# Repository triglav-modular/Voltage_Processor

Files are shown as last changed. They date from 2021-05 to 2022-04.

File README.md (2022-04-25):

# Triglav Modular Voltage Processor
Eurorack voltage processor / ring modulator inspired by the Buchla 257.

Features:

* Two independent channels, each mixing an attenuverter, a voltage-controlled crossfader and an offset voltage (0-5V).
* „Ring” switches turn the crossfaders into ring modulators / bipolar VCAs.
* S-curve attenuverters for easier nulling.
* Can be trimmed precisely for 1V/oct signals
* LEDs indicating negative/positive voltage.

Other notes:
* Crossfader expects a 0-8V envelope in regular mode.
* Turning on the ring switch normalizes an inverted copy of the inputs into each other. This allows the crossfader to be used as a second attenuverter, a bipolar VCA or a ring modulator with adjustable bias without any additonal patching.
* 11 HP, compact design
* Panel + PCB sandwich, suitable for skiffs
* Reverse polarity protection
* Open source




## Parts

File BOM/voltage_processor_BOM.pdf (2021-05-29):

Designator | Package | Quantity | Value

Resistors

R72,R69,R28,R71,R30,R33,R74,R31 0805 | 8 | 220R
R21,R90,R48,R49,R44,R85 | 0805 | 6 | 1K
R4,R2,R3,R1 | 0805 | 4 | 2K2
R106,R105,R109,R108 | 0805 | 4 | 4K7
R7,R8,R5,R6,R89,R104 | 0805 | 6 | 10K
R36,R39 | 0805 | 2 | 80K
R78,R37,R45,R96 | 0805 | 4 | 49K9
R26,R68,R75,R22,R102,R63,R103,R10,R19,R15,R52,R38,R18,R88,R13,R51,R27,R70,R50,R67,R12,R35,R56,R54,R62,R40,R43,R24,R29,R59,R65,R87,R41,R82,R11,R60,R53,R73,R47,R34,R95,R46,R76,R42 0805 | 44 | 100K
R58,R61,R16,R23,R25,R55,R66,R17,R20,R64,R14,R57 0805 | 12 | 200K
R110,R107 | 0805 | 2 | 442K
R32,R9 | 0805 | 2 | 10M

Capacitors

C54,C70 | 0805 | 2 | 33p
CS | 0805 | 15 | do not fit or 33p
C27,C10,C29,C12 | 0805 | 4 | 100p
C31,C30,C15,C28,C32,C11,C13,C14 0805 | 8 | 1200p
C25,C62,C46,C68,C56,C36,C23,C52,C21,C55,C22,C35,C20,C61,C24,C6,C67,C37,C45,C38,C5,C18,C51,C19 0805 | 24 | 0.1µ
C1,C4,C3,C2 | Ø4x5.8mm (Panasonic B) eg. EEEFT1E220AR 4 | 22µ

Semiconductors

U1,U9,U8,U11,U4,U5 | SOIC-14 | 6 | OPA4134 / TL074
IC3,IC2,IC4,IC1 | SOIC-16 | 4 | DG212BDY
U10,U6 | SOIC-16 | 2 | SSI2164
D1,D2 | D_SOD-123 | 2 | 1N5819
Q3,Q1 | SOT-23-3 | 2 | 3906
Q4,Q2 | SOT-23-3 | 2 | 3904
U2 | SOT-89-3 | 1 | L78L05
D6,D3,D4,D5 | LED 3.0mm | 4 | LED
D7,D8,D9,D10 | D_SOD-323 | 4 | Zener 5.1V

Miscellaneous

| Alpha 9mm vertical potentiometer | 6 | B10K
| THONKICONN Jacks | 10
| Eurorack Keyed Header | 1 | 30310-6002HB
ATV_COMP2,CRSFD2,ATV_COMP1,LED1+1,LED2+1,LED2-1,LED1-1,CRSFD1 BOURNS 3362P TRIMMER | 8 | 100K
S1,S2 | 108-2MS1T1B1M2QE-EVX | 2 | SPDT Sub-Miniature Toggle Switch
PinHeader_1x10_P2.54mm_Vertical2 | Conn_01x10_Female
PinHeader_1x10_P2.54mm_Vertical2 | Conn_01x10_Male
PinHeader_1x16_P2.54mm_Vertical1 | Conn_01x16_Male
PinHeader_1x16_P2.54mm_Vertical1 | Conn_01x16_Female

1

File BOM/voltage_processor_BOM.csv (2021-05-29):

Id | Designator | Package | Quantity | Designation | Supplier and ref
1 | R26,R68,R75,R22,R102,R63,R103,R10,R19,R15,R52,R38,R18,R88,R13,R51,R27,R70,R50,R67,R12,R35,R56,R54,R62,R40,R43,R24,R29,R59,R65,R87,R41,R82,R11,R60,R53,R73,R47,R34,R95,R46,R76,R42 | R_0805_2012Metric | 44 | 100K
2 | R78,R37,R45,R96 | R_0805_2012Metric | 4 | 49K9
3 | ATV_COMP2,CRSFD2,ATV_COMP1,LED1+1,LED2+1,LED2-1,LED1-1,CRSFD1 | BOURNS_3362P_TRIMMER | 8 | 100K
4 | R58,R61,R16,R23,R25,R55,R66,R17,R20,R64,R14,R57 | R_0805_2012Metric | 12 | 200K
5 | IC3,IC2,IC4,IC1 | SOIC-16_3.9x9.9mm_P1.27mm | 4 | DG212BDY
6 | J10,J14 | THONKICONN | 2 | OUTPUT
7 | J7,J11 | THONKICONN | 2 | CROSSFADE_CV
8 | R72,R69,R28,R71,R30,R33,R74,R31 | R_0805_2012Metric | 8 | 220R
9 | C1,C4,C3,C2 | CAPAE430X610N | 4 | 22µ
10 | C31,C30,C15,C28,C32,C11,C13,C14 | C_0805_2012Metric | 8 | 1200p
11 | OFFSET2,OFFSET1,ATNVRT2,ATNVRT1,CROSSFADE2,CROSSFADE1 | MusicThingModular-9MM_SNAP-IN_POT | 6 | B10K
12 | D6,D3,D4,D5 | LED_D3.0mm | 4 | LED
13 | MH8,MH7,MH4,MH2,MH5,MH3,MH6,MH1 | MountingHole_3.2mm_M3 | 8 | MountingHole_3.2mm_M3
14 | R7,R8,R5,R6,R89,R104 | R_0805_2012Metric | 6 | 10K
15 | R21,R90,R48,R49,R44,R85 | R_0805_2012Metric | 6 | 1K
16 | J1,J2 | THONKICONN | 2 | ATNVRT_IN_BOTTOM
17 | R106,R105,R109,R108 | R_0805_2012Metric | 4 | 4K7
18 | J17 | SHDR10W64P254_2X5_2030X878X930P | 1 | 30310-6002HB
19 | U1,U9,U8,U11,U4,U5 | SOIC-14_3.9x8.7mm_P1.27mm | 6 | OPA4134
20 | D7,D8,D9,D10 | D_SOD-323_HandSoldering_ZENER | 4 | Z-5V
21 | R36,R39 | R_0805_2012Metric | 2 | 80K
22 | Q3,Q1 | SOT-23-3 | 2 | 3906
23 | R32,R9 | R_0805_2012Metric | 2 | 10Meg
24 | mouse-bite-2mm-slot_3,mouse-bite-2mm-slot_2,mouse-bite-2mm-slot_1 | mouse-bite-2mm-slot | 3 | VAL**
25 | U10,U6 | SOIC-16_3.9x9.9mm_P1.27mm | 2 | SSI2164
26 | Q4,Q2 | SOT-23-3 | 2 | 3904
27 | J9,J13 | THONKICONN | 2 | CROSSFADE_B
28 | D1,D2 | D_SOD-123 | 2 | 1N5819
29 | J12,J8 | THONKICONN | 2 | CROSSFADE_A
30 | S1,S2 | 1082MS1T1B1M2QEEVX | 2 | 108-2MS1T1B1M2QE-EVX
31 | U2 | SOT-89-3 | 1 | L78L05
32 | C25,C62,C46,C68,C56,C36,C23,C52,C21,C55,C22,C35,C20,C61,C24,C6,C67,C37,C45,C38,C5,C18,C51,C19 | C_0805_2012Metric | 24 | 0.1µ
33 | C8,C42,C66,C7,C43,C50,C63,C65,C64,C59,C17,C47,C48,C49,C58 | C_0805_2012Metric | 15 | CS
34 | R4,R2,R3,R1 | R_0805_2012Metric | 4 | 2K2
35 | J5 | PinHeader_1x16_P2.54mm_Vertical | 1 | Conn_01x16_Male
36 | J6,J4 | PinHeader_1x10_P2.54mm_Vertical | 2 | Conn_01x10_Female
37 | R110,R107 | R_0805_2012Metric | 2 | 442K
38 | J15,J16 | PinHeader_1x10_P2.54mm_Vertical | 2 | Conn_01x10_Male
39 | C27,C10,C29,C12 | C_0805_2012Metric | 4 | 100p
40 | J3 | PinHeader_1x16_P2.54mm_Vertical | 1 | Conn_01x16_Female
41 | C54,C70 | C_0805_2012Metric | 2 | 33p

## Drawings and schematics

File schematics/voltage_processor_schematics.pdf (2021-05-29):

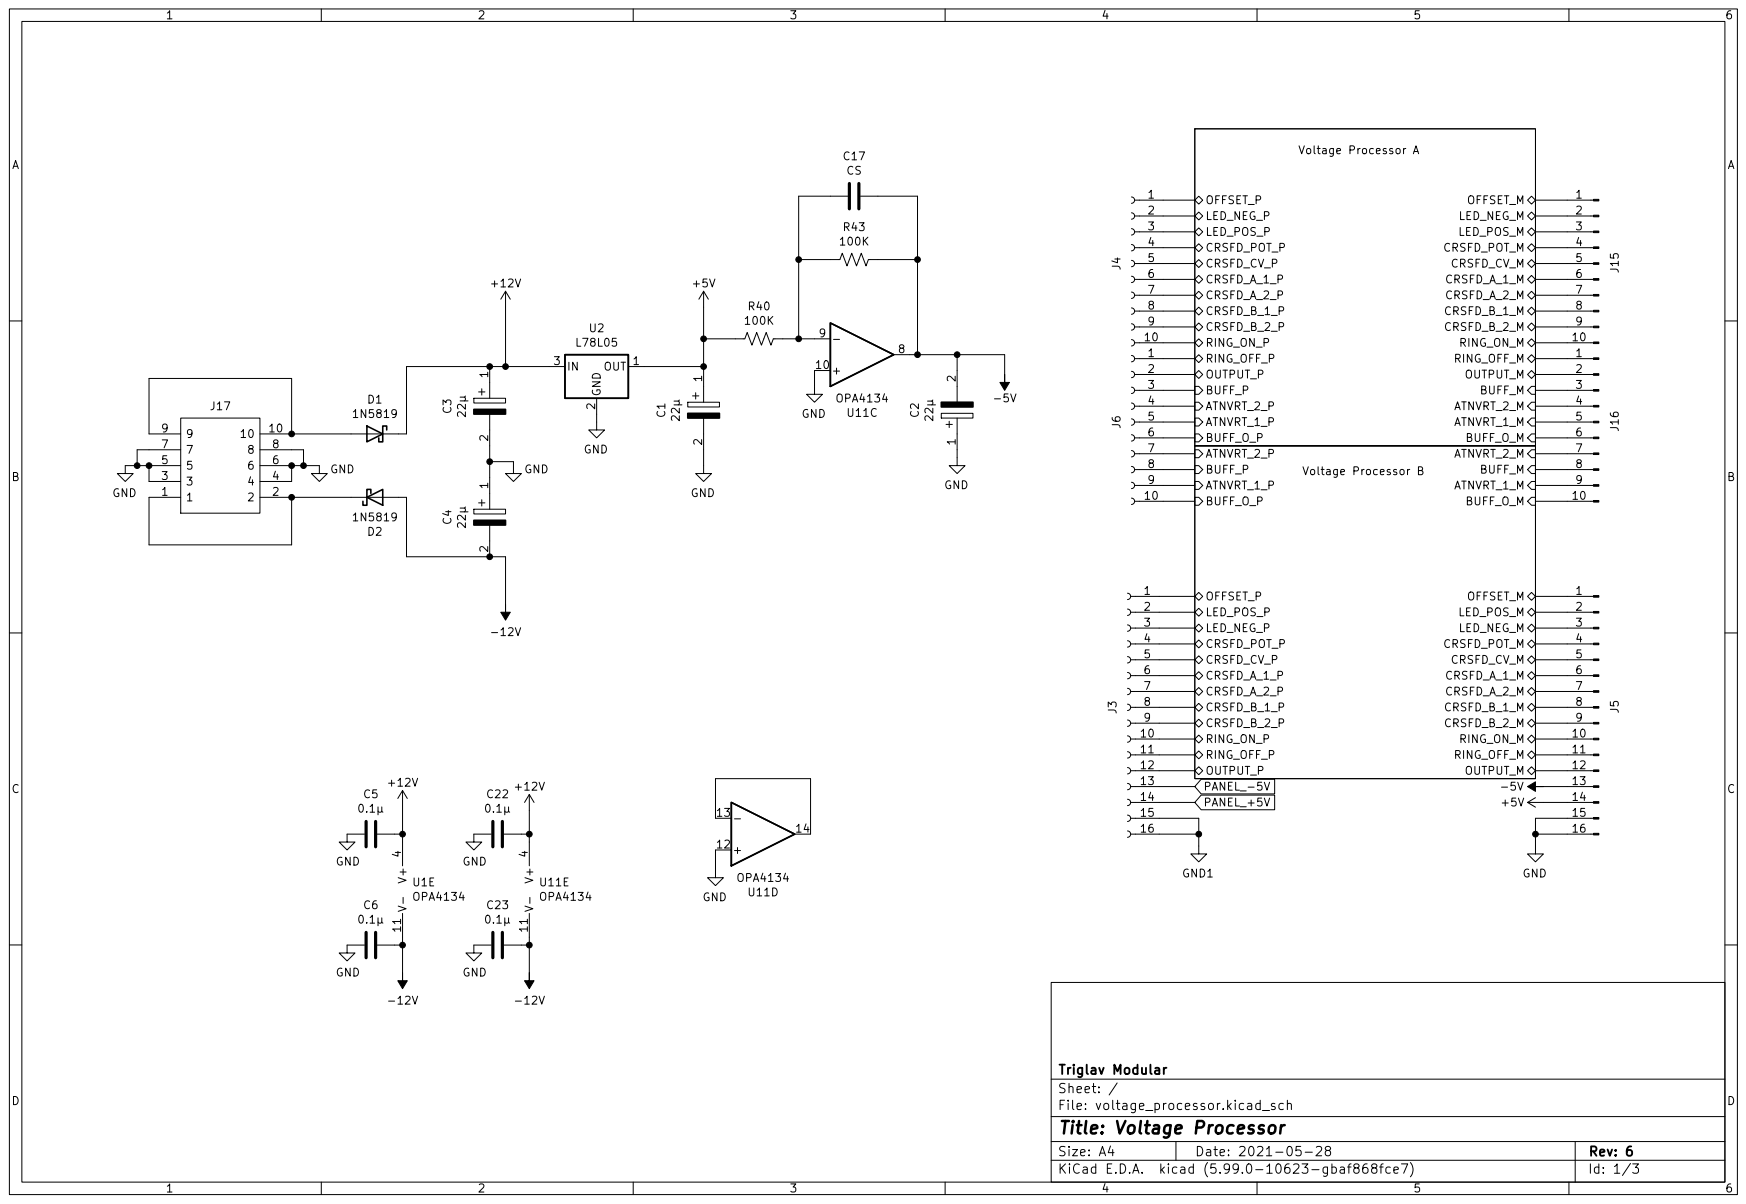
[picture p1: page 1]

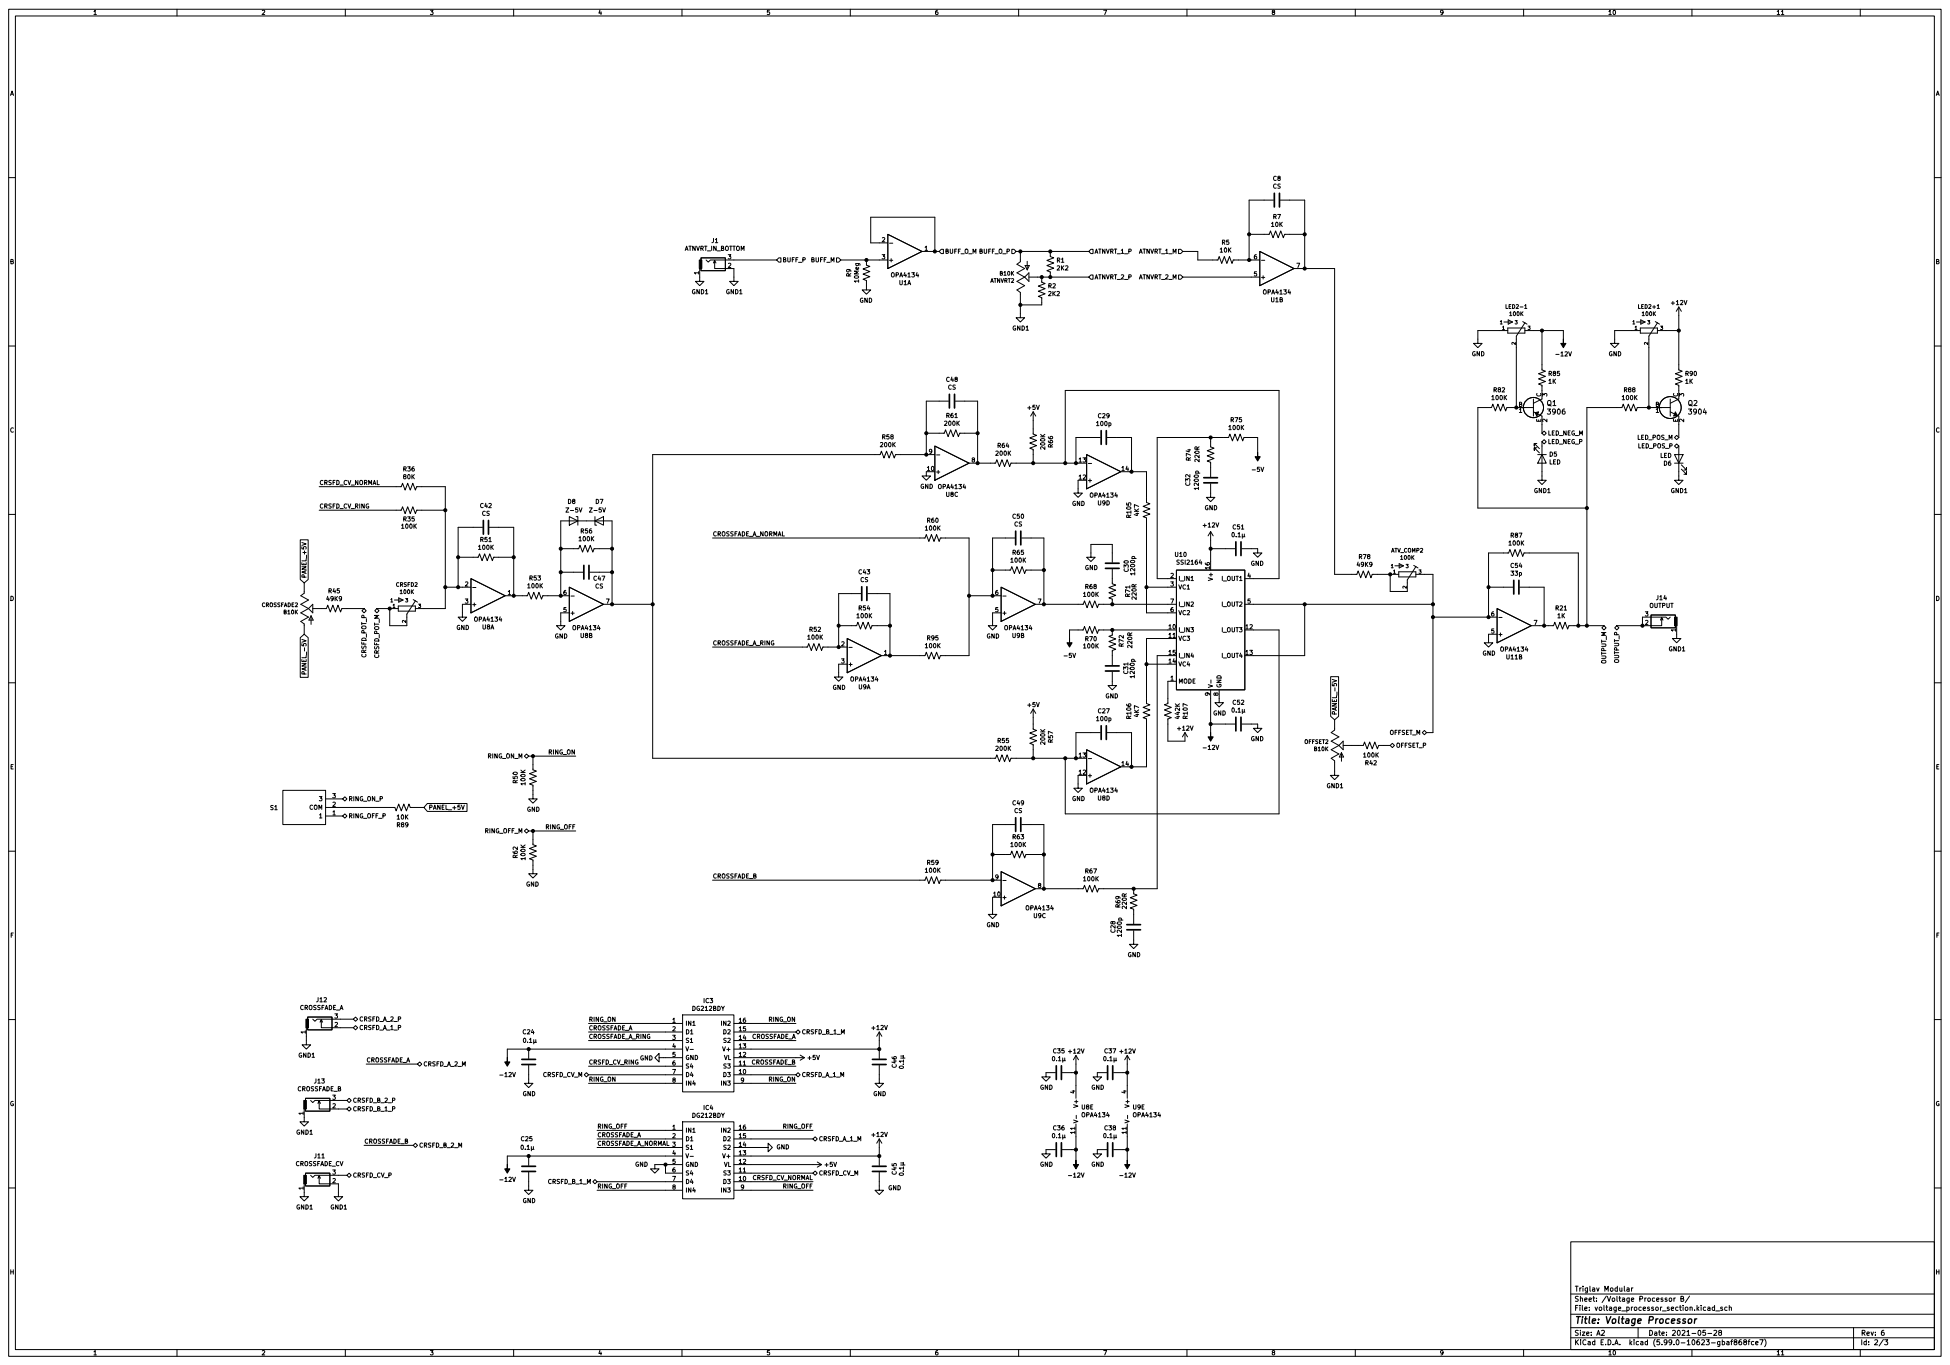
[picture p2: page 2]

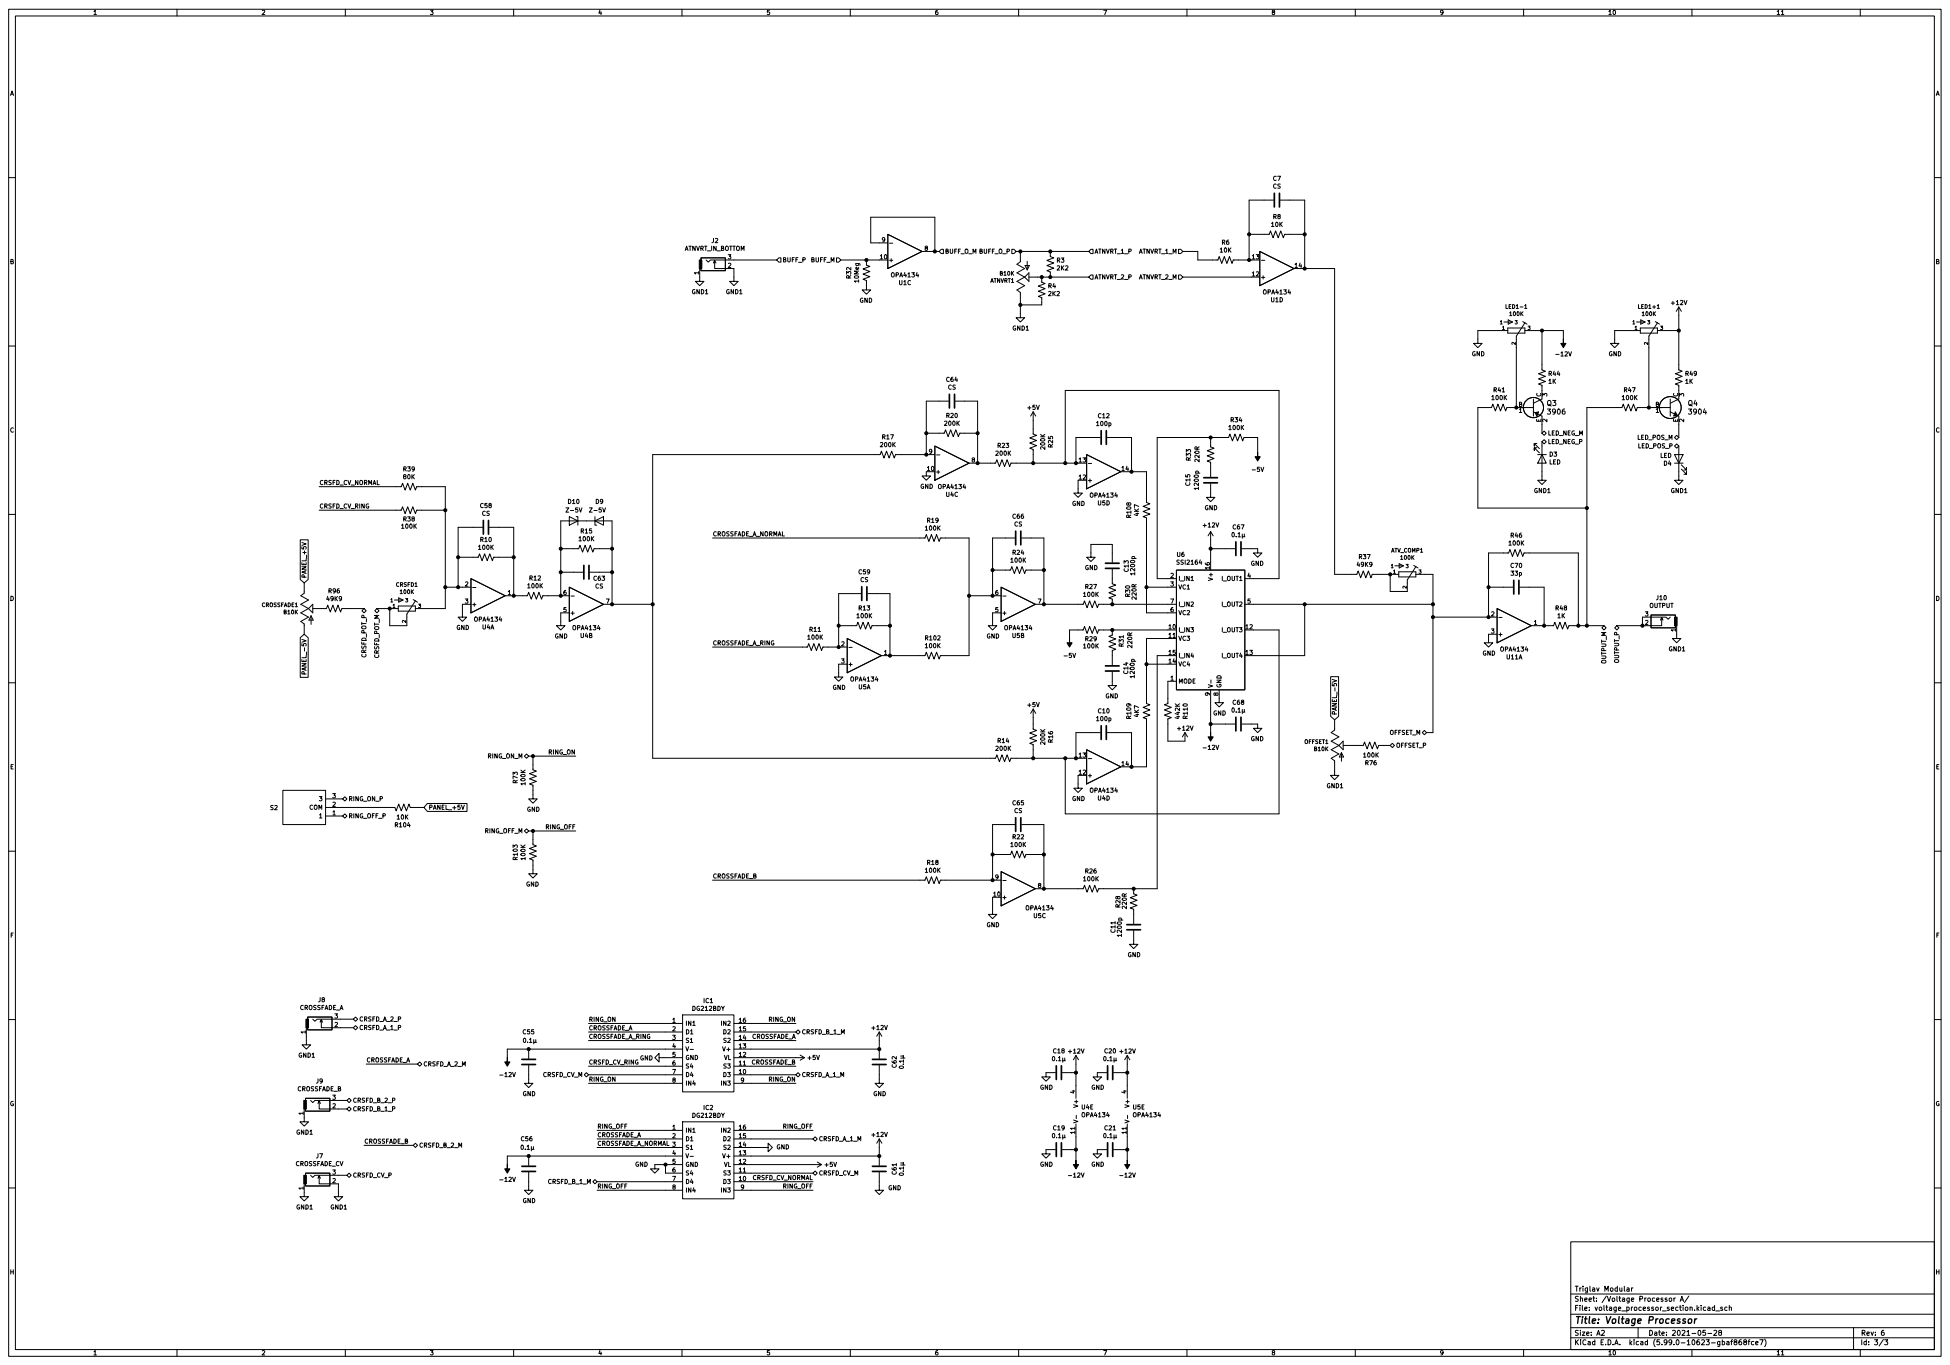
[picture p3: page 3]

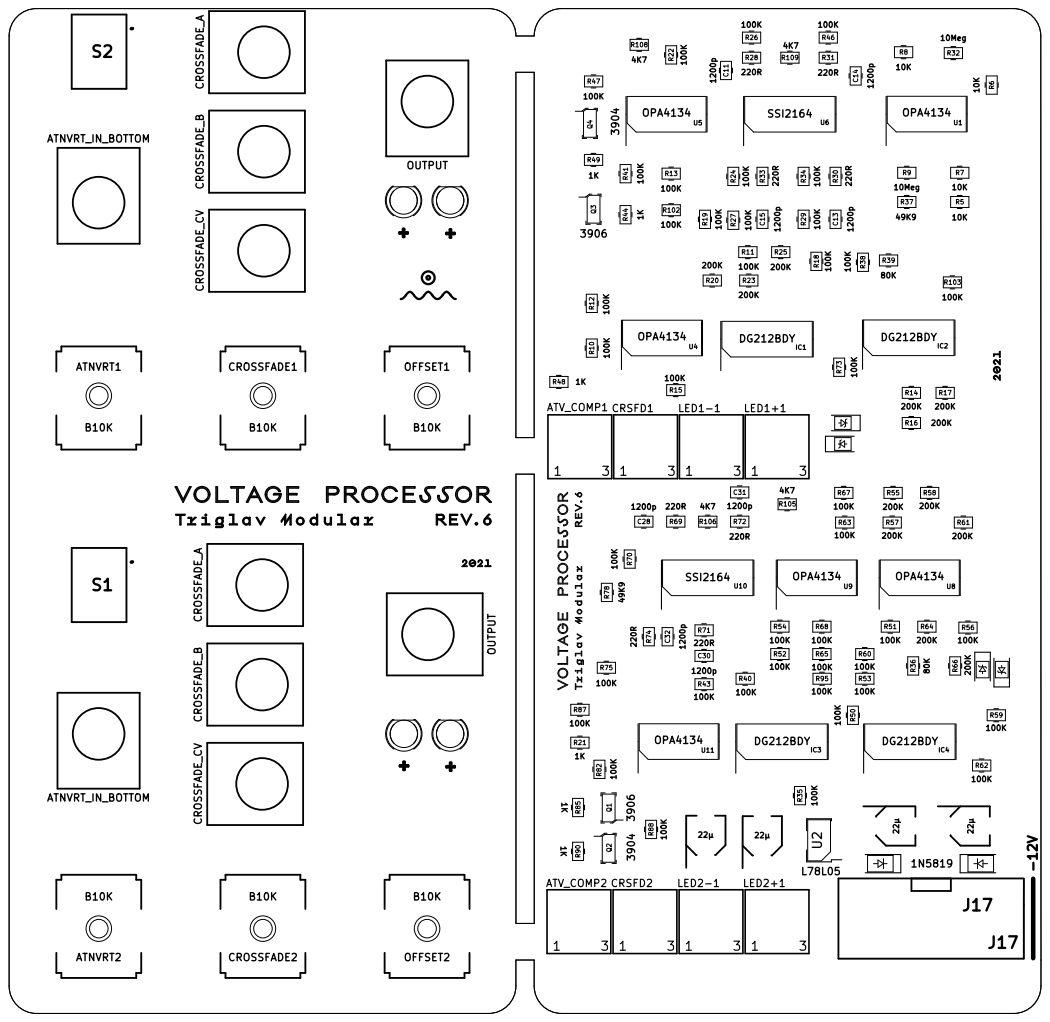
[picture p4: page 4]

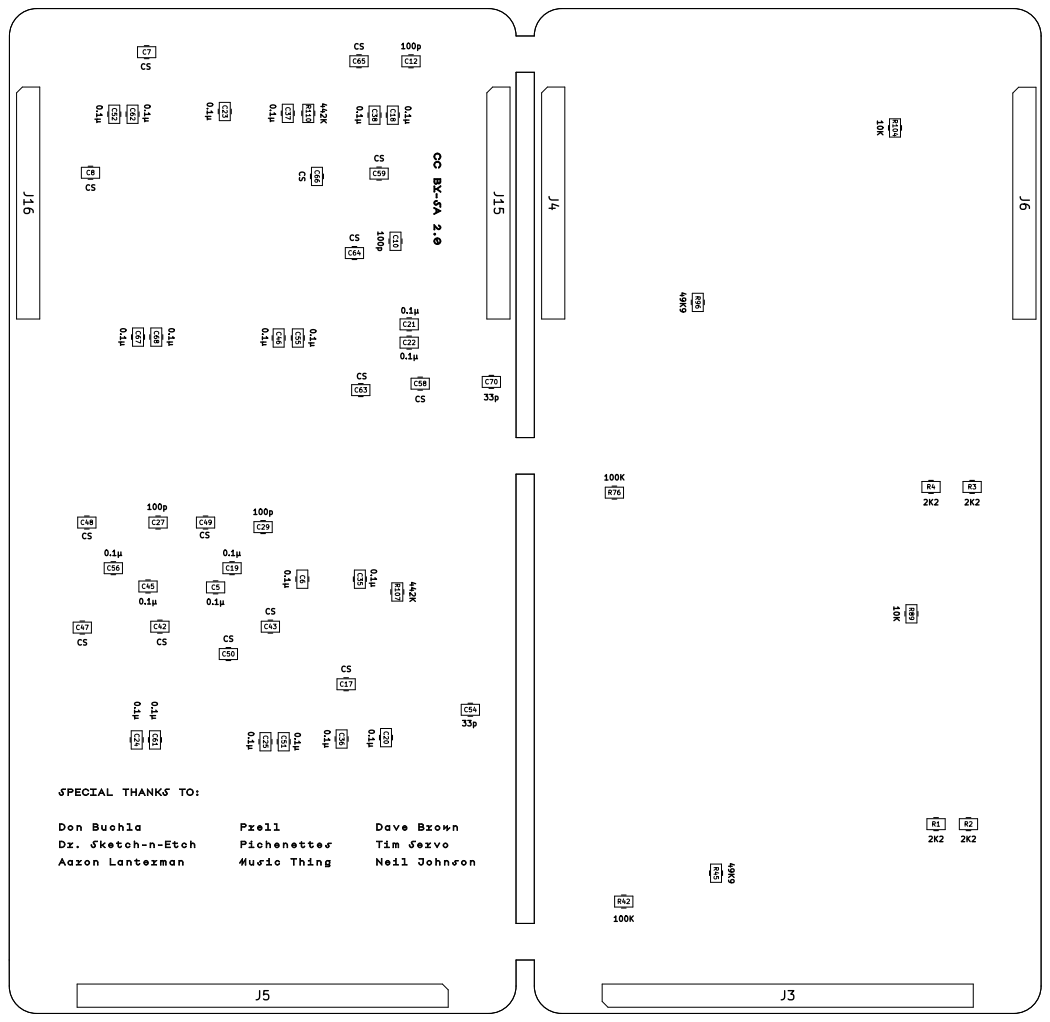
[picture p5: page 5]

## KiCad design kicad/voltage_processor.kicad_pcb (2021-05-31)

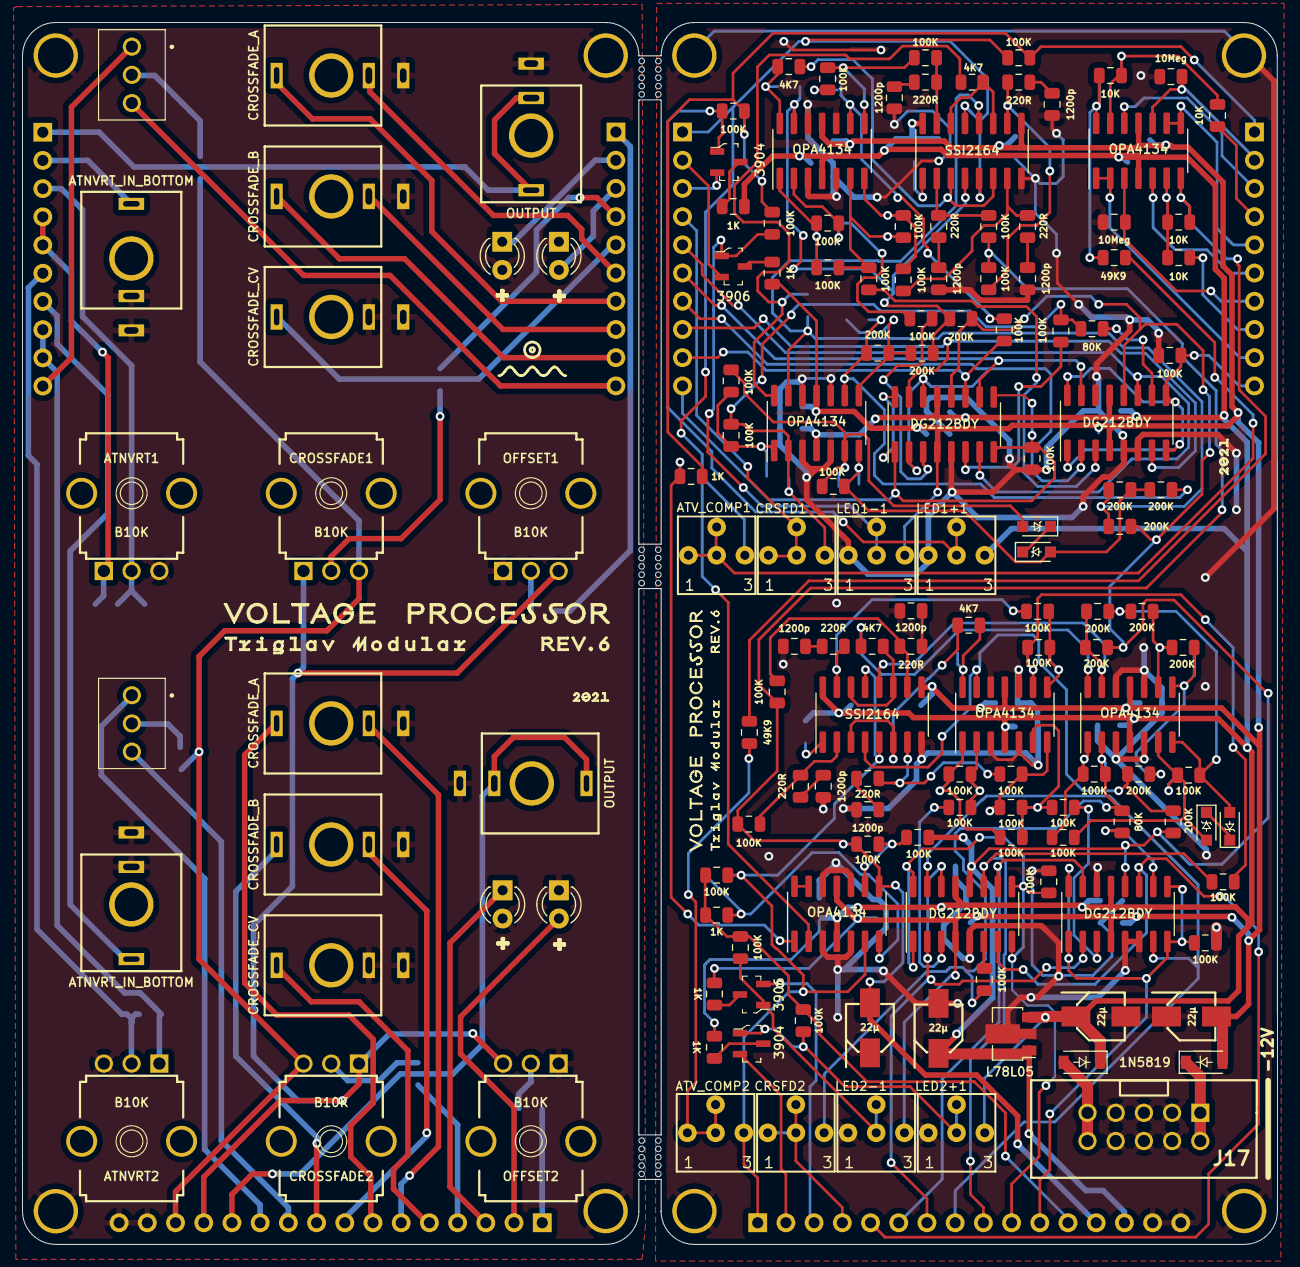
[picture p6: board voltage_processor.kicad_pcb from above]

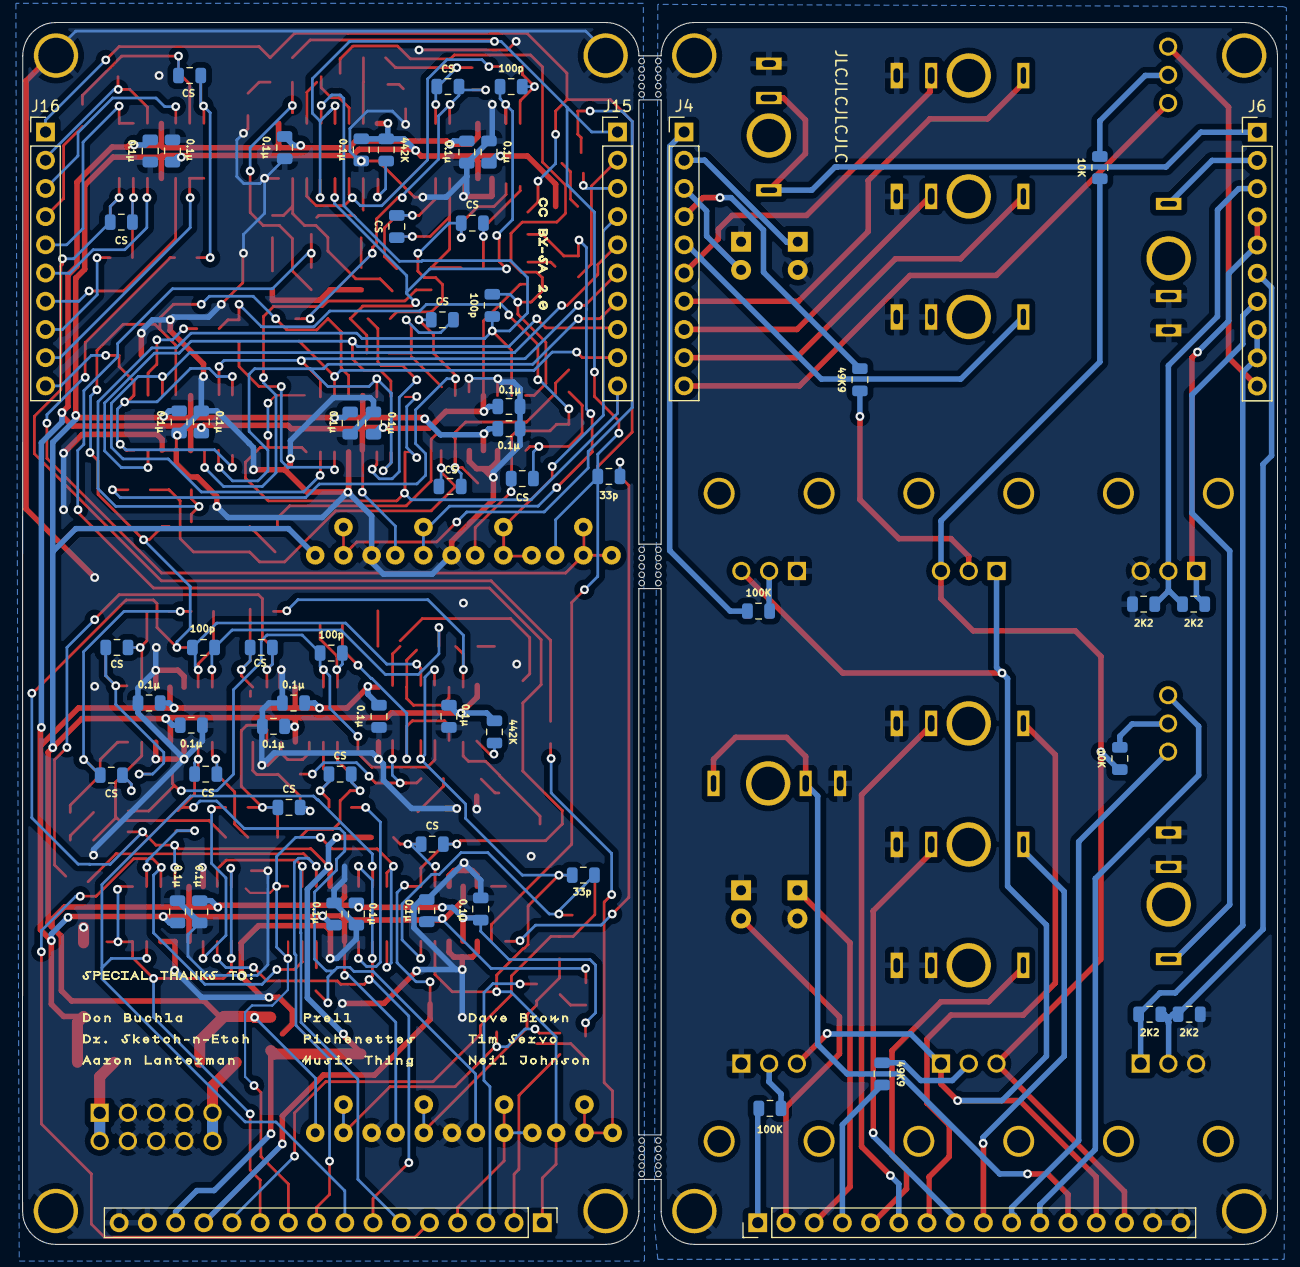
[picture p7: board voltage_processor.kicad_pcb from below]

Board: 2 copper layers, 113.0 x 110.0 mm, 222 parts (63 on the bottom side), 160 nets.

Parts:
ATNVRT1, ATNVRT2: B10K; MusicThingModular-9MM_SNAP-IN_POT
ATV_COMP1, ATV_COMP2: 100K; BOURNS_3362P_TRIMMER
C1, C2, C3, C4: 22µ; CAPAE430X610N
C5, C6, C18, C19, C20, C21, C22, C23, C24, C25, C35, C36, C37, C38, C45, C46, C51, C52, C55, C56, C61, C62, C67, C68: 0.1µ; C_0805_2012Metric
C7, C8, C17, C42, C43, C47, C48, C49, C50, C58, C59, C63, C64, C65, C66: CS; C_0805_2012Metric
C10, C12, C27, C29: 100p; C_0805_2012Metric
C11, C13, C14, C15, C28, C30, C31, C32: 1200p; C_0805_2012Metric
C54, C70: 33p; C_0805_2012Metric
CROSSFADE1, CROSSFADE2: B10K; MusicThingModular-9MM_SNAP-IN_POT
CRSFD1, CRSFD2: 100K; BOURNS_3362P_TRIMMER
D1, D2: 1N5819; D_SOD-123
D3, D4, D5, D6: LED; LED_D3.0mm
D7, D8, D9, D10: Z-5V; D_SOD-323_HandSoldering_ZENER
IC1, IC2, IC3, IC4: DG212BDY; SOIC-16_3.9x9.9mm_P1.27mm
J1, J2: ATNVRT_IN_BOTTOM; THONKICONN
J3: Conn_01x16_Female; PinHeader_1x16_P2.54mm_Vertical
J4, J6: Conn_01x10_Female; PinHeader_1x10_P2.54mm_Vertical
J5: Conn_01x16_Male; PinHeader_1x16_P2.54mm_Vertical
J7, J11: CROSSFADE_CV; THONKICONN
J8, J12: CROSSFADE_A; THONKICONN
J9, J13: CROSSFADE_B; THONKICONN
J10, J14: OUTPUT; THONKICONN
J15, J16: Conn_01x10_Male; PinHeader_1x10_P2.54mm_Vertical
J17: 30310-6002HB; SHDR10W64P254_2X5_2030X878X930P
LED1+1, LED1-1, LED2+1, LED2-1: 100K; BOURNS_3362P_TRIMMER
MH1, MH2, MH3, MH4, MH5, MH6, MH7, MH8: MountingHole_3.2mm_M3
OFFSET1, OFFSET2: B10K; MusicThingModular-9MM_SNAP-IN_POT
Q1, Q3: 3906; SOT-23-3
Q2, Q4: 3904; SOT-23-3
R1, R2, R3, R4: 2K2; R_0805_2012Metric
R5, R6, R7, R8, R89, R104: 10K; R_0805_2012Metric
R9, R32: 10Meg; R_0805_2012Metric
R10, R11, R12, R13, R15, R18, R19, R22, R24, R26, R27, R29, R34, R35, R38, R40, R41, R42, R43, R46, R47, R50, R51, R52, R53, R54, R56, R59, R60, R62, R63, R65, R67, R68, R70, R73, R75, R76, R82, R87, R88, R95, R102, R103: 100K; R_0805_2012Metric
R14, R16, R17, R20, R23, R25, R55, R57, R58, R61, R64, R66: 200K; R_0805_2012Metric
R21, R44, R48, R49, R85, R90: 1K; R_0805_2012Metric
R28, R30, R31, R33, R69, R71, R72, R74: 220R; R_0805_2012Metric
R36, R39: 80K; R_0805_2012Metric
R37, R45, R78, R96: 49K9; R_0805_2012Metric
R105, R106, R108, R109: 4K7; R_0805_2012Metric
R107, R110: 442K; R_0805_2012Metric
S1, S2: 108-2MS1T1B1M2QE-EVX; 1082MS1T1B1M2QEEVX
U1, U4, U5, U8, U9, U11: OPA4134; SOIC-14_3.9x8.7mm_P1.27mm
U2: L78L05; SOT-89-3
U6, U10: SSI2164; SOIC-16_3.9x9.9mm_P1.27mm
mouse-bite-2mm-slot_1, mouse-bite-2mm-slot_2, mouse-bite-2mm-slot_3: VAL**; mouse-bite-2mm-slot

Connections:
+5V: C1.1, IC1.12 (VL), IC2.12 (VL), IC3.12 (VL), IC4.12 (VL), J5.14, R16.2, R25.2, R40.2, R57.2, R66.2, U2.1 (OUT)
+12V: C3.1, C5.1, C18.1, C20.1, C22.1, C35.1, C37.1, C45.1, C46.2, C51.1, C61.1, C62.2, C67.1, D1.1 (K), IC1.13 (V+), IC2.13 (V+), IC3.13 (V+), IC4.13 (V+), LED1+1.3, LED2+1.3, R49.1, R90.1, R107.2, R110.2, U1.4 (V+), U2.3 (IN), U4.4 (V+), U5.4 (V+), U6.16 (V+), U8.4 (V+), U9.4 (V+), U10.16 (V+), U11.4 (V+)
-5V: C2.2, C17.1, J5.13, R29.2, R34.2, R43.1, R70.2, R75.2, U11.8
-12V: C4.2, C6.1, C19.1, C21.1, C23.1, C24.1, C25.1, C36.1, C38.1, C52.1, C55.1, C56.1, C68.1, D2.2 (A), IC1.4 (V-), IC2.4 (V-), IC3.4 (V-), IC4.4 (V-), LED1-1.3, LED2-1.3, R44.1, R85.1, U1.11 (V-), U4.11 (V-), U5.11 (V-), U6.9 (V-), U8.11 (V-), U9.11 (V-), U10.9 (V-), U11.11 (V-)
/Voltage Processor A/ATNVRT_1_M: J16.5, R6.2
/Voltage Processor A/ATNVRT_1_P: ATNVRT1.1 (A), J6.5, J6.6, R3.1
/Voltage Processor A/ATNVRT_2_M: J16.4, U1.12 (+)
/Voltage Processor A/ATNVRT_2_P: ATNVRT1.2 (S), J6.4, R3.2, R4.1
/Voltage Processor A/BUFF_M: J16.3, R32.1, U1.10 (+)
/Voltage Processor A/BUFF_O_M: J16.6, U1.8, U1.9 (-)
/Voltage Processor A/BUFF_P: J2.3, J6.3
/Voltage Processor A/CROSSFADE_A: IC1.2 (D1), IC1.14 (S2), IC2.2 (D1), J15.7
/Voltage Processor A/CROSSFADE_A_NORMAL: IC2.3 (S1), R19.2
/Voltage Processor A/CROSSFADE_A_RING: IC1.3 (S1), R11.2
/Voltage Processor A/CROSSFADE_B: IC1.11 (S3), J15.9, R18.2
/Voltage Processor A/CRSFD_A_1_M: IC1.10 (D3), IC2.15 (D2), J15.6
/Voltage Processor A/CRSFD_A_1_P: J4.6, J8.2
/Voltage Processor A/CRSFD_A_2_P: J4.7, J8.3
/Voltage Processor A/CRSFD_B_1_M: IC1.15 (D2), IC2.7 (D4), J15.8
/Voltage Processor A/CRSFD_B_1_P: J4.8, J9.2
/Voltage Processor A/CRSFD_B_2_P: J4.9, J9.3
/Voltage Processor A/CRSFD_CV_M: IC1.7 (D4), IC2.11 (S3), J15.5
/Voltage Processor A/CRSFD_CV_NORMAL: IC2.10 (D3), R39.2
/Voltage Processor A/CRSFD_CV_P: J4.5, J7.3
/Voltage Processor A/CRSFD_CV_RING: IC1.6 (S4), R38.1
/Voltage Processor A/CRSFD_POT_M: CRSFD1.1, CRSFD1.2, J15.4
/Voltage Processor A/CRSFD_POT_P: J4.4, R96.1
/Voltage Processor A/LED_NEG_M: J15.2, Q3.2 (E)
/Voltage Processor A/LED_NEG_P: D3.1 (K), J4.2
/Voltage Processor A/LED_POS_M: J15.3, Q4.2 (E)
/Voltage Processor A/LED_POS_P: D4.2 (A), J4.3
/Voltage Processor A/OFFSET_M: ATV_COMP1.3, C70.2, J15.1, R46.2, U6.5 (I_OUT2), U6.13 (I_OUT4), U11.2 (-)
/Voltage Processor A/OFFSET_P: J4.1, R76.2
/Voltage Processor A/OUTPUT_M: J16.2, R41.2, R46.1, R47.2, R48.1
/Voltage Processor A/OUTPUT_P: J6.2, J10.2, J10.3
/Voltage Processor A/RING_OFF: IC2.1 (IN1), IC2.8 (IN4), IC2.9 (IN3), IC2.16 (IN2), J16.1, R103.2
/Voltage Processor A/RING_OFF_P: J6.1, S2.1
/Voltage Processor A/RING_ON: IC1.1 (IN1), IC1.8 (IN4), IC1.9 (IN3), IC1.16 (IN2), J15.10, R73.2
/Voltage Processor A/RING_ON_P: J4.10, S2.3
/Voltage Processor B/ATNVRT_1_M: J16.9, R5.2
/Voltage Processor B/ATNVRT_1_P: ATNVRT2.1 (A), J6.9, J6.10, R1.1
/Voltage Processor B/ATNVRT_2_M: J16.7, U1.5 (+)
/Voltage Processor B/ATNVRT_2_P: ATNVRT2.2 (S), J6.7, R1.2, R2.1
/Voltage Processor B/BUFF_M: J16.8, R9.1, U1.3 (+)
/Voltage Processor B/BUFF_O_M: J16.10, U1.1, U1.2 (-)
/Voltage Processor B/BUFF_P: J1.3, J6.8
/Voltage Processor B/CROSSFADE_A: IC3.2 (D1), IC3.14 (S2), IC4.2 (D1), J5.7
/Voltage Processor B/CROSSFADE_A_NORMAL: IC4.3 (S1), R60.2
/Voltage Processor B/CROSSFADE_A_RING: IC3.3 (S1), R52.2
/Voltage Processor B/CROSSFADE_B: IC3.11 (S3), J5.9, R59.2
/Voltage Processor B/CRSFD_A_1_M: IC3.10 (D3), IC4.15 (D2), J5.6
/Voltage Processor B/CRSFD_A_1_P: J3.6, J12.2
/Voltage Processor B/CRSFD_A_2_P: J3.7, J12.3
/Voltage Processor B/CRSFD_B_1_M: IC3.15 (D2), IC4.7 (D4), J5.8
/Voltage Processor B/CRSFD_B_1_P: J3.8, J13.2
/Voltage Processor B/CRSFD_B_2_P: J3.9, J13.3
/Voltage Processor B/CRSFD_CV_M: IC3.7 (D4), IC4.11 (S3), J5.5
/Voltage Processor B/CRSFD_CV_NORMAL: IC4.10 (D3), R36.2
/Voltage Processor B/CRSFD_CV_P: J3.5, J11.3
/Voltage Processor B/CRSFD_CV_RING: IC3.6 (S4), R35.1
/Voltage Processor B/CRSFD_POT_M: CRSFD2.1, CRSFD2.2, J5.4
/Voltage Processor B/CRSFD_POT_P: J3.4, R45.1
/Voltage Processor B/LED_NEG_M: J5.3, Q1.2 (E)
/Voltage Processor B/LED_NEG_P: D5.1 (K), J3.3
/Voltage Processor B/LED_POS_M: J5.2, Q2.2 (E)
/Voltage Processor B/LED_POS_P: D6.2 (A), J3.2
/Voltage Processor B/OFFSET_M: ATV_COMP2.3, C54.2, J5.1, R87.2, U10.5 (I_OUT2), U10.13 (I_OUT4), U11.6 (-)
/Voltage Processor B/OFFSET_P: J3.1, R42.2
/Voltage Processor B/OUTPUT_M: J5.12, R21.1, R82.2, R87.1, R88.2
/Voltage Processor B/OUTPUT_P: J3.12, J14.2, J14.3
/Voltage Processor B/RING_OFF: IC4.1 (IN1), IC4.8 (IN4), IC4.9 (IN3), IC4.16 (IN2), J5.11, R62.2
/Voltage Processor B/RING_OFF_P: J3.11, S1.1
/Voltage Processor B/RING_ON: IC3.1 (IN1), IC3.8 (IN4), IC3.9 (IN3), IC3.16 (IN2), J5.10, R50.2
/Voltage Processor B/RING_ON_P: J3.10, S1.3
GND: C1.2, C2.1, C3.2, C4.1, C5.2, C6.2, C11.1, C13.1, C14.1, C15.1, C18.2, C19.2, C20.2, C21.2, C22.2, C23.2, C24.2, C25.2, C28.1, C30.1, C31.1, C32.1, C35.2, C36.2, C37.2, C38.2, C45.2, C46.1, C51.2, C52.2, C55.2, C56.2, C61.2, C62.1, C67.2, C68.2, IC1.5 (GND), IC2.5 (GND), IC2.6 (S4), IC2.14 (S2), IC3.5 (GND), IC4.5 (GND), IC4.6 (S4), IC4.14 (S2), J5.15, J5.16, J17.3, J17.4, J17.5, J17.6, J17.7, J17.8, LED1+1.1, LED1-1.1, LED2+1.1, LED2-1.1, R9.2, R32.2, R50.1, R62.1, R73.1, R103.1, U2.2 (GND), U4.3 (+), U4.5 (+), U4.10 (+), U4.12 (+), U5.3 (+), U5.5 (+), U5.10 (+), U5.12 (+), U6.8 (GND), U8.3 (+), U8.5 (+), U8.10 (+), U8.12 (+), U9.3 (+), U9.5 (+), U9.10 (+), U9.12 (+), U10.8 (GND), U11.3 (+), U11.5 (+), U11.10 (+), U11.12 (+)
GND1: ATNVRT1.3 (E), ATNVRT2.3 (E), D3.2 (A), D4.1 (K), D5.2 (A), D6.1 (K), J1.1, J1.2, J2.1, J2.2, J3.15, J3.16, J7.1, J7.2, J8.1, J9.1, J10.1, J11.1, J11.2, J12.1, J13.1, J14.1, OFFSET1.1 (A), OFFSET2.1 (A), R2.2, R4.2
unnamed: ATV_COMP1.1, ATV_COMP1.2, R37.1
unnamed: ATV_COMP2.1, ATV_COMP2.2, R78.1
unnamed: C7.1, R8.1, R37.2, U1.14
unnamed: C7.2, R6.1, R8.2, U1.13 (-)
unnamed: C8.1, R7.1, R78.2, U1.7
unnamed: C8.2, R5.1, R7.2, U1.6 (-)
unnamed: C10.1, R109.2, U4.14
unnamed: C10.2, R14.1, R16.1, U4.13 (-), U6.12 (I_OUT3)
unnamed: C11.2, R28.2
unnamed: C12.1, R108.1, U5.14
unnamed: C12.2, R23.1, R25.1, U5.13 (-), U6.4 (I_OUT1)
unnamed: C13.2, R30.2
unnamed: C14.2, R31.2
unnamed: C15.2, R33.2
unnamed: C17.2, R40.1, R43.2, U11.9 (-)
unnamed: C27.1, R106.2, U8.14
unnamed: C27.2, R55.1, R57.1, U8.13 (-), U10.12 (I_OUT3)
unnamed: C28.2, R69.2
unnamed: C29.1, R105.1, U9.14
unnamed: C29.2, R64.1, R66.1, U9.13 (-), U10.4 (I_OUT1)
unnamed: C30.2, R71.2
unnamed: C31.2, R72.2
unnamed: C32.2, R74.2
unnamed: C42.1, R51.1, R53.2, U8.1
unnamed: C42.2, CRSFD2.3, R35.2, R36.1, R51.2, U8.2 (-)
unnamed: C43.1, R54.1, R95.2, U9.1
unnamed: C43.2, R52.1, R54.2, U9.2 (-)
unnamed: C47.1, D7.2 (A), R55.2, R56.1, R58.2, U8.7
unnamed: C47.2, D8.2 (A), R53.1, R56.2, U8.6 (-)
unnamed: C48.1, R61.1, R64.2, U8.8
unnamed: C48.2, R58.1, R61.2, U8.9 (-)
unnamed: C49.1, R63.1, R67.2, U9.8
unnamed: C49.2, R59.1, R63.2, U9.9 (-)
unnamed: C50.1, R65.1, R68.2, U9.7
unnamed: C50.2, R60.1, R65.2, R95.1, U9.6 (-)
unnamed: C54.1, R21.2, U11.7
unnamed: C58.1, R10.1, R12.2, U4.1
unnamed: C58.2, CRSFD1.3, R10.2, R38.2, R39.1, U4.2 (-)
unnamed: C59.1, R13.1, R102.2, U5.1
unnamed: C59.2, R11.1, R13.2, U5.2 (-)
unnamed: C63.1, D9.2 (A), R14.2, R15.1, R17.2, U4.7
unnamed: C63.2, D10.2 (A), R12.1, R15.2, U4.6 (-)
unnamed: C64.1, R20.1, R23.2, U4.8
unnamed: C64.2, R17.1, R20.2, U4.9 (-)
unnamed: C65.1, R22.1, R26.2, U5.8
unnamed: C65.2, R18.1, R22.2, U5.9 (-)
unnamed: C66.1, R24.1, R27.2, U5.7
unnamed: C66.2, R19.1, R24.2, R102.1, U5.6 (-)
unnamed: C70.1, R48.2, U11.1
unnamed: CROSSFADE1.2 (S), R96.2
unnamed: CROSSFADE2.2 (S), R45.2
unnamed: D1.2 (A), J17.9, J17.10
unnamed: D2.1 (K), J17.1, J17.2
unnamed: D7.1 (K), D8.1 (K)
unnamed: D9.1 (K), D10.1 (K)
unnamed: LED1+1.2, Q4.1 (B), R47.1
unnamed: LED1-1.2, Q3.1 (B), R41.1
unnamed: LED2+1.2, Q2.1 (B), R88.1
unnamed: LED2-1.2, Q1.1 (B), R82.1
unnamed: OFFSET1.2 (S), R76.1
unnamed: OFFSET2.2 (S), R42.1
unnamed: Q1.3 (C), R85.2
unnamed: Q2.3 (C), R90.2
unnamed: Q3.3 (C), R44.2
unnamed: Q4.3 (C), R49.2
unnamed: R26.1, R28.1, U6.15 (I_IN4)
unnamed: R27.1, R30.1, U6.7 (I_IN2)
unnamed: R29.1, R31.1, U6.10 (I_IN3)
unnamed: R33.1, R34.1, U6.2 (I_IN1)
unnamed: R67.1, R69.1, U10.15 (I_IN4)
unnamed: R68.1, R71.1, U10.7 (I_IN2)
unnamed: R70.1, R72.1, U10.10 (I_IN3)
unnamed: R74.1, R75.1, U10.2 (I_IN1)
unnamed: R89.1, S1.2 (COM)
unnamed: R104.1, S2.2 (COM)
unnamed: R105.2, U10.3 (VC1), U10.6 (VC2)
unnamed: R106.1, U10.11 (VC3), U10.14 (VC4)
unnamed: R107.1, U10.1 (MODE)
unnamed: R108.2, U6.3 (VC1), U6.6 (VC2)
unnamed: R109.1, U6.11 (VC3), U6.14 (VC4)
unnamed: R110.1, U6.1 (MODE)
unnamed: U11.13 (-), U11.14
PANEL_+5V: CROSSFADE1.3 (E), CROSSFADE2.3 (E), J3.14, R89.2, R104.2
PANEL_-5V: CROSSFADE1.1 (A), CROSSFADE2.1 (A), J3.13, OFFSET1.3 (E), OFFSET2.3 (E)
